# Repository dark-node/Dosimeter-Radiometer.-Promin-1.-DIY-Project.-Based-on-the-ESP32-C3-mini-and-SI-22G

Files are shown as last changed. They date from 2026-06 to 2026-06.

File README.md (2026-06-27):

# Промінь-1 — γ-дозиметр на СІ-22Г / Promin-1 — SI-22G gamma dosimeter

**🇺🇦 Українська** | [🇬🇧 English](README.en.md)

Портативний побутовий гамма-дозиметр на базі лічильної трубки Гейгера–Мюллера
**СІ-22Г** та мікроконтролера **ESP32-C3 Super Mini**.

> ⚠️ **Hobby-проєкт.** Це не сертифікований і не еталонно відкалібрований
> прилад. Не покладайтеся на нього у питаннях здоров'я чи безпеки.
> Зроблено *only for fun*.

## 🎬 Демонстрація роботи

<video src="https://github.com/dark-node/Dosimeter-Radiometer.-Promin-1.-DIY-Project.-Based-on-the-ESP32-C3-mini-and-SI-22G/raw/main/media/demo-test.mp4" controls width="640" poster="media/photos-final/front-view.jpg">
  Ваш переглядач не підтримує вбудоване відео.
</video>

📹 Якщо відео не відтворюється тут — [відкрити / завантажити відео тесту](media/demo-test.mp4)

---

## Можливості

- Реєстрація імпульсів трубки через апаратне переривання (GPIO ISR).
- Розрахунок **CPM** (вікна 60 с і 10 с) та потужності дози **мкЗв/год**.
- OLED-дисплей SSD1306 128×32, три режими: `мкЗв/год`, `CPM`, `cnt`.
- Звуковий клік (п'єзо) і світлодіодний спалах на кожен імпульс.
- Індикація заряду акумулятора (резистивний дільник, опит раз на 2 хв).
- Заставка при старті (2 с).

## Технічні параметри

| Параметр | Значення |
|---|---|
| Трубка | СІ-22Г (гамма) |
| Висока напруга | ~405 В (готовий DC-DC модуль) |
| Анодний баласт | 10 МОм |
| Зняття імпульсу | з катода, формувач на BC547B → GPIO2 |
| Калібрування | 800 CPM на 1 мкЗв/год |
| Фон | ≈0.10–0.12 мкЗв/год |
| MCU | ESP32-C3 Super Mini |
| Дисплей | OLED SSD1306 128×32, I2C 400 кГц |
| Живлення | Li-ion 18650 |

Повний опис, історія розробки та BOM — у [`docs/Description.txt`](docs/Description.txt).

## Розводка GPIO (ESP32-C3)

| GPIO | Призначення |
|---|---|
| 2 | Вхід імпульсів СІ-22Г (ISR) |
| 3 | ADC заряду АКБ |
| 4 / 5 | OLED SDA / SCL |
| 6 | Світлодіод (через 330 Ω) |
| 7 / 10 | П'єзо (push-pull) |
| 8 / 9 / 20 | Кнопки: CPM / мкЗв·год / лічильник |
| 3V3 | Живлення OLED (НЕ 5 В) |

Схема детектора:

```
HV+ ──[10M]── анод СІ-22Г ── катод ── DET
DET ──[10k]── GND
DET ──[470nF]──[50k]── база BC547B ──[4.7M]── GND
емітер ── GND
колектор ──[15k]── 3V3,  відгалуження → GPIO2
```

> ⚡ Не використовувати GPIO0, GPIO1, GPIO21 (boot/UART).
> Спільна земля: ESP, HV-модуль, катод трубки, емітер транзистора.

## Структура репозиторію

```
.
├── firmware/             # Прошивка ESP-IDF (C/C++)
│   └── main/main.cpp
├── hardware/
│   ├── schematics/       # LTspice: схема з'єднань + симуляції
│   └── 3d-models/        # STL/Blender корпусу + renders/
├── media/
│   ├── photos-final/     # Фото готового пристрою
│   ├── photos-build/     # Фото процесу збірки
│   └── demo-test.mp4     # Відео тесту роботи
├── docs/
│   ├── Description.txt    # Опис, історія, BOM, специфікація
│   └── splash.png         # Вихідне зображення заставки OLED
├── LICENSE               # MIT
├── README.md             # Українська (цей файл)
└── README.en.md          # English
```

## Складання та прошивка

Потрібен [ESP-IDF](https://docs.espressif.com/projects/esp-idf/). У теці `firmware/`:

```bash
idf.py set-target esp32c3
idf.py build
idf.py flash monitor
```

## Схема (LTspice)

Файл [`hardware/schematics/promin1-connections.asc`](hardware/schematics/promin1-connections.asc)
— схема з'єднань для збірки (довідник, не для симуляції).

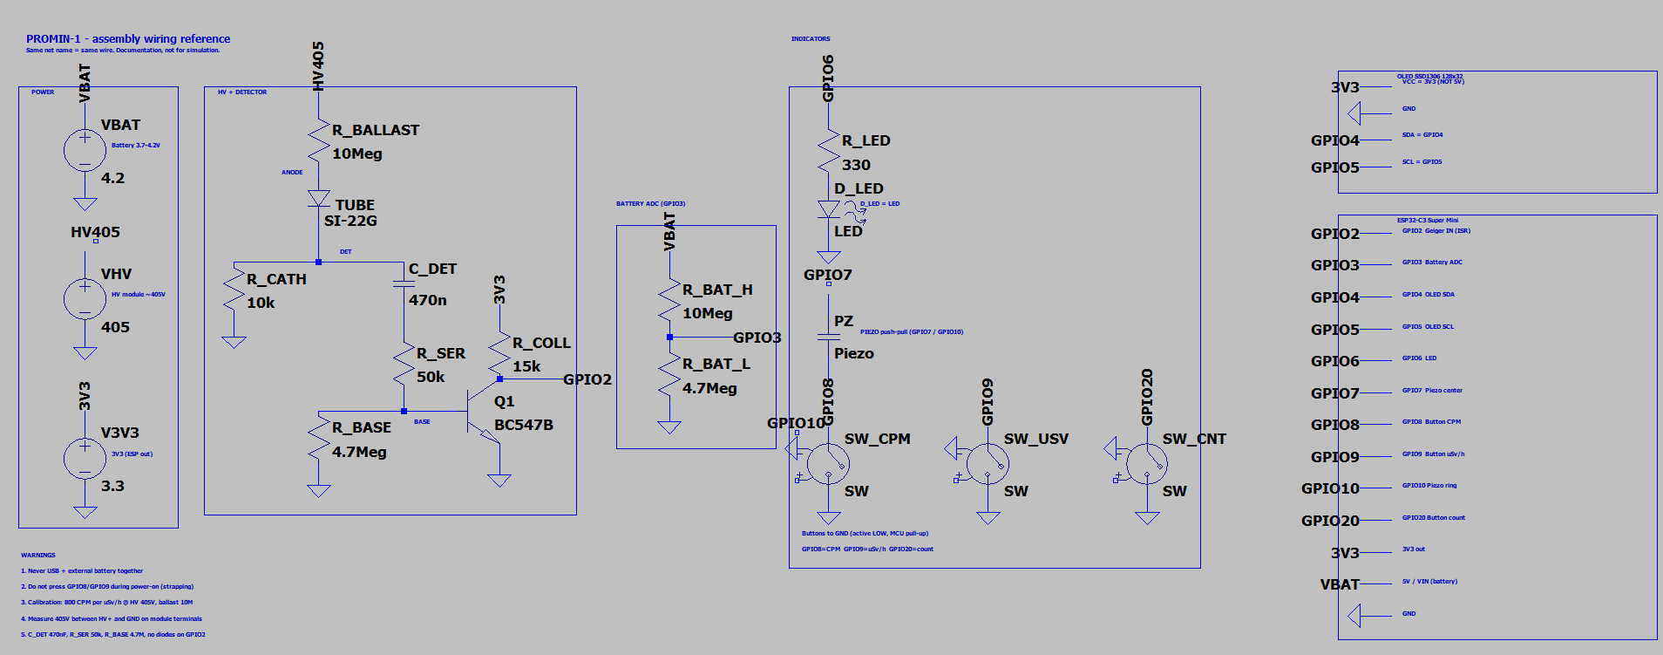
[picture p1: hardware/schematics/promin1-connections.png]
Schematic


## Галерея

| | | |
|---|---|---|
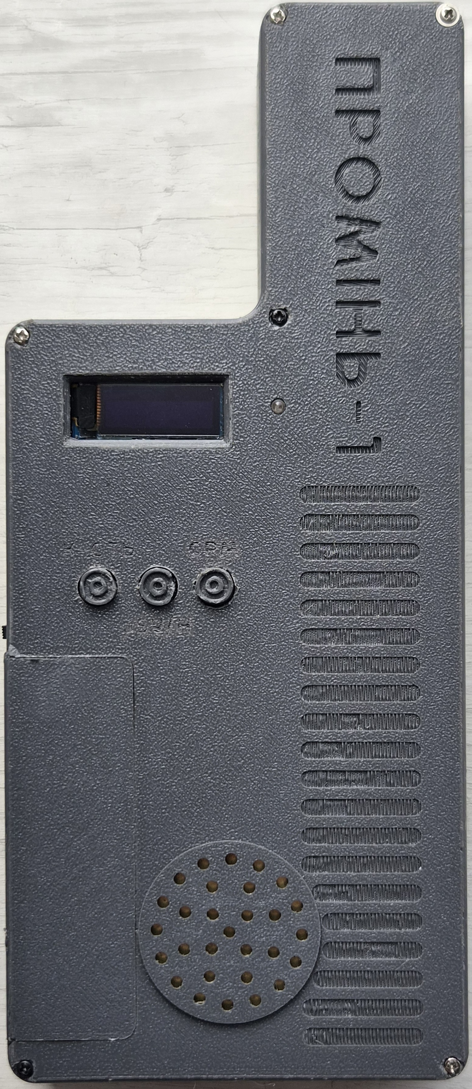
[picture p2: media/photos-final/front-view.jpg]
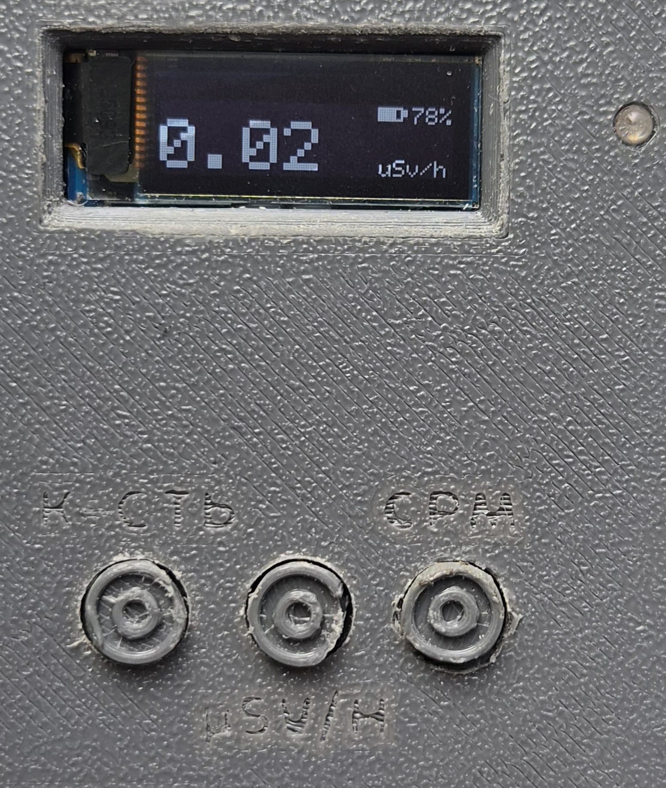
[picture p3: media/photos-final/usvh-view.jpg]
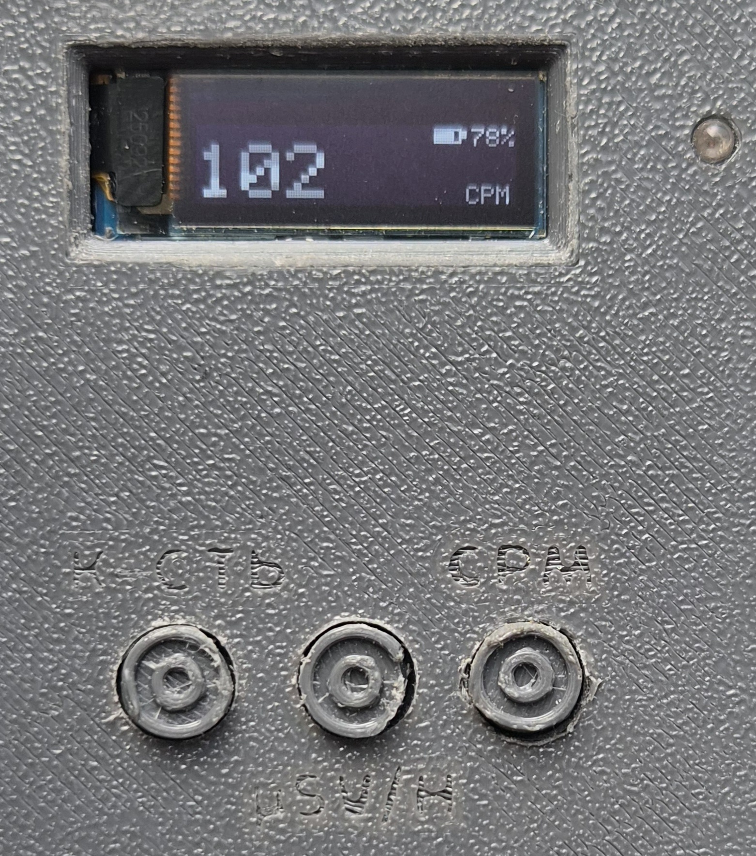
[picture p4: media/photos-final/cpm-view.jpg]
|  |  |  |
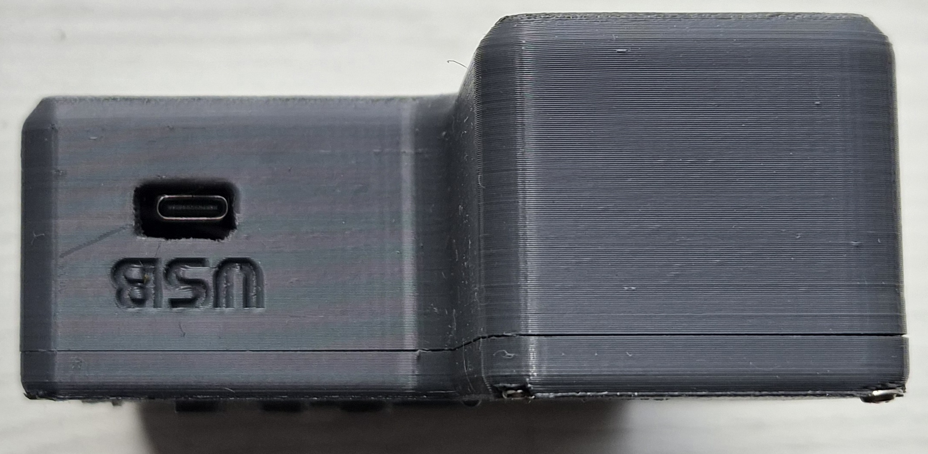
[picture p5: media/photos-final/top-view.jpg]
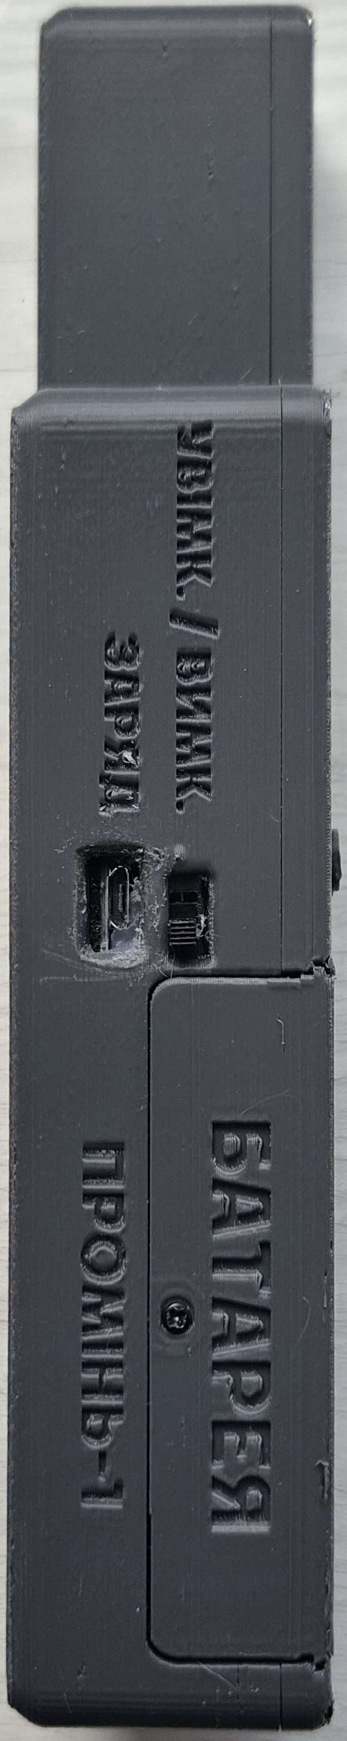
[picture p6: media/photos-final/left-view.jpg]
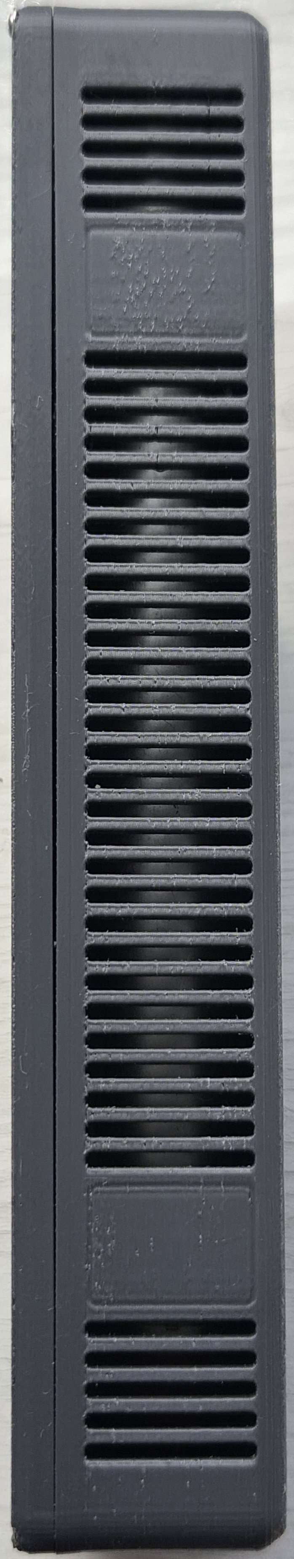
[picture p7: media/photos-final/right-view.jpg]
|  |  |  |

3D-моделі корпусу: [`hardware/3d-models/`](hardware/3d-models/)

## Ліцензія

[MIT](LICENSE). Hobby-пристрій, use at your own risk.

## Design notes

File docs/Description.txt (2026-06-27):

================================================================
ПРОМІНЬ-1 — портативний гамма-дозиметр на СІ-22Г
================================================================

--------------------------------
ВІД АВТОРА
--------------------------------

Збірка дозиметра «Промінь-1» за своєю суттю — лише хобійний експеримент.
Корисної інформації в цьому проєкті доволі мало, і немає жодних наукових
відкриттів. Більше того, професіонали своєї справи можуть дуже легко знайти
слабкі або неправильні місця — і будуть цілком праві. Цей проєкт фактично є
здійсненням дитячої мрії з тих часів, коли я вперше навчився паяти, — і не
більше того.

Тому радіоаматори можуть «захейтити» за надто грубий спосіб зняття імпульсів
та за використання готового модуля високої напруги замість намотування власних
котушок — але це й не було прямою метою цієї роботи. Своєю чергою, любителі
радіодозиметрії можуть «захейтити» за відсутність другого, еталонного дозиметра
й за неточність роботи пристрою. Але повторюся: ця робота була створена only
for fun і супернаукової цінності не несе.

Саме через це було обрано трубку СІ-22Г: вона дешева, до того ж куплена «з рук»
(вживана). Щоправда, через це довелося доволі сильно збільшити розміри готового
виробу. Знімати імпульси довелося з катода (хоча там вони на порядок слабші);
при цьому були спроби зняти сигнал як транзистором, так і оптопарою — спрацював
лише один варіант. Анодний спосіб навіть не довелося пробувати. А калібрування
(через відсутність еталонного пристрою) довелося робити за станціями, що
вимірюють радіацію в моїй зоні проживання, — тому ймовірність похибки в цьому
пристрої доволі велика. Більше того, довелося підвищувати напругу до 420–440 В
(у фінальній версії подається 405 В) через «заюзаність» самої трубки, яка
фактично за паспортних умов видає лише близько 30–40 імпульсів (а мала б 60+).

Також для тих, хто захоче повторити: обов'язково майте набір резисторів,
особливо кілоомних, — тому що під вашу конкретну трубку доведеться підбирати
такий опір, щоб імпульси, які ви знімаєте, мали достатню амплітуду й були
помітні для вашого MCU.

Щодо візуалу — так-так, 3D-друк вийшов доволі поганеньким, але передруковувати
не бачу великого сенсу: у ролі корпусу він функціонує нормально, та й подальша
доля цього дозиметра — лежати в шафі. Можливо, через деякий час він навіть буде
розібраний на компоненти. Тому для цієї ролі все чудово підходить і так.

Декілька слів про MCU. Спочатку для збірки використовувалася ESP32-H2 — з тієї
причини, що вона просто була в мене. Але в процесі роботи вона перестала
адекватно працювати, тому було вирішено не витрачати ні час, ні гроші, а взяти з
іншого проєкту ESP32-C3, яка більше підходить для виконання цього завдання, а
також лишає можливість додати Wi-Fi-підключення й модифікувати дозиметр для
роботи через хот-спот. Але це не було реалізовано (мені то й не треба).

--------------------------------
ОПИС ПРОЄКТУ
--------------------------------

«Промінь-1» — портативний лічильник іонізуючого випромінювання (побутовий
гамма-дозиметр) на базі радянської лічильної трубки Гейгера-Мюллера СІ-22Г та
мікроконтролера ESP32-C3 Super Mini.

Принцип роботи:
  1. DC-DC модуль підвищує напругу живлення до ~405 В для роботи трубки.
  2. Кожна зареєстрована частинка викликає короткий розряд у трубці.
  3. Імпульс знімається з катода, формується транзистором BC547B і подається
     на вхід MCU (GPIO2) як перепад рівня, що обробляється через апаратне
     переривання (GPIO ISR).
  4. Прошивка рахує імпульси, обчислює CPM (за вікно 60 с і за вікно 10 с) та
     переводить у потужність дози (мкЗв/год) за калібрувальним коефіцієнтом.
  5. Результат виводиться на OLED-дисплей; кожен імпульс супроводжується кліком
     п'єзовипромінювача та спалахом світлодіода.

Режими відображення (перемикаються кнопками):
  - мкЗв/год  — потужність дози (за усередненим CPM60), екран за замовчуванням;
  - CPM       — швидкий темп лічби (за вікно 10 с);
  - cnt       — сумарна кількість зареєстрованих імпульсів.

Додатково на екрані відображається рівень заряду акумулятора (вимірюється через
резистивний дільник раз на 2 хв).

Калібрування: GEIGER_CPM_PER_USVH = 800 (≈100 CPM60 ≈ 0.126 мкЗв/год за фоном,
звірено зі станцією Safecast 126 нЗв/год). Через вживану трубку та відсутність
еталона точність орієнтовна.

--------------------------------
ЩО ВИКОРИСТОВУВАЛОСЬ
--------------------------------

Апаратне забезпечення:
  - Мікроконтролер ESP32-C3 Super Mini (RISC-V, Wi-Fi/BLE — не задіяні).
  - Трубка Гейгера-Мюллера СІ-22Г (гамма, вживана).
  - Готовий DC-DC модуль високої напруги (вхід 5 В, вихід ~405 В).
  - OLED-дисплей SSD1306 128x32, інтерфейс I2C.
  - Акумулятор Li-ion 18650.

Інструменти та ПЗ:
  - ESP-IDF (фреймворк, мова C/C++), збірка через idf.py.
  - LTspice — схема з'єднань для збірки (файл Schematic/Promin1.asc).
  - 3D-друк корпусу (моделі в теці 3D_models).
  - Паяння методом «навісного монтажу» (point-to-point), згодом — на платі.

--------------------------------
СПИСОК КОМПОНЕНТІВ (BOM)
--------------------------------

  Поз.        Номінал / тип        К-сть   Призначення
  ----------  -------------------  ------  -------------------------------------
  MCU         ESP32-C3 Super Mini    1     Керування, лічба, дисплей
  Трубка      СІ-22Г                 1     Детектор гамма-випромінювання
  HV-модуль   DC-DC ~405 В (вх.5В)   1     Висока напруга для трубки
  Дисплей     OLED SSD1306 128x32    1     Індикація (I2C)
  АКБ         Li-ion 18650           1     Живлення
  Q1          BC547B (NPN)           1     Формувач імпульсу з катода
  R_BALLAST   10 МОм                 1     Анодний баласт (HV+ → анод)
  R_CATH      10 кОм                 1     Катодне навантаження (DET → GND)
  R_SER       50 кОм                 1     Послідовний у базу (через C_DET)
  R_BASE      4.7 МОм                1     Зміщення/стік бази → GND
  R_COLL      15 кОм                 1     Колектор → 3.3 В (підтяжка)
  R_LED       330 Ом                 1     Струмообмеження світлодіода
  R_BAT_H     10 МОм                 1     Верхнє плече дільника АКБ
  R_BAT_L     4.7 МОм                1     Нижнє плече дільника АКБ
  C_DET       470 нФ                 1     Розв'язка катод → база
  D_LED       Світлодіод             1     Індикація імпульсів
  Піщалка     П'єзовипромінювач      1     Звуковий клік (push-pull)
  Кнопки      Тактові, на GND        3     Перемикання режимів
  ----------  -------------------  ------  -------------------------------------

  Примітка: кілоомні номінали (R_CATH, R_SER) підбираються індивідуально під
  конкретну трубку — тримайте під рукою набір резисторів.

--------------------------------
СПЕЦИФІКАЦІЯ / РОЗВОДКА GPIO
--------------------------------

  Детектор:
    HV+ ──[R_BALLAST 10M]── анод СІ-22Г ── катод ── DET
    DET ──[R_CATH 10k]── GND
    DET ──[C_DET 470n]──[R_SER 50k]── база BC547B
    база ──[R_BASE 4.7M]── GND
    емітер ── GND
    колектор ──[R_COLL 15k]── 3.3 В,  відгалуження → GPIO2

  Дільник вимірювання АКБ:
    VBAT ──[R_BAT_H 10M]── GPIO3 ──[R_BAT_L 4.7M]── GND

  Призначення виводів ESP32-C3 (мітка на платі = номер GPIO):
    GPIO2   — вхід імпульсів СІ-22Г (через ISR, спадний фронт)
    GPIO3   — ADC вимірювання заряду АКБ
    GPIO4   — OLED SDA (I2C)
    GPIO5   — OLED SCL (I2C)
    GPIO6   — світлодіод (через 330 Ом)
    GPIO7   — п'єзо, центральний (push-pull, фаза A)
    GPIO8   — кнопка «CPM»
    GPIO9   — кнопка «мкЗв/год» (екран)
    GPIO10  — п'єзо, кільце (push-pull, фаза B)
    GPIO20  — кнопка «лічильник»
    3V3     — живлення OLED (НЕ 5 В!)
    5V/VIN  — від акумулятора
    GND     — спільна земля

  Не використовувати: GPIO0, GPIO1, GPIO21 (boot/UART).
  Спільна земля: ESP, HV-модуль, катод трубки, емітер транзистора.

  Ключові параметри прошивки:
    - Висока напруга:            405 В (вимір між HV+ і GND на модулі)
    - Калібрування:              800 CPM на 1 мкЗв/год
    - Вікна усереднення:         60 с (доза) і 10 с (швидкий CPM)
    - Антидребезг трубки:        2500 мкс
    - Опитування АКБ:            раз на 2 хв
    - Заставка при старті:       2 с (інвертовані кольори)
    - Дисплей:                   SSD1306 128x32, I2C 400 кГц

--------------------------------
СТРУКТУРА РЕПОЗИТОРІЮ
--------------------------------

  Promin1/         — прошивка ESP-IDF (main/main.cpp, splash_bitmap.h)
  Schematic/       — схема з'єднань для LTspice (Promin1.asc)
  3D_models/       — моделі корпусу для друку (+ Img з рендерами)
  Final_Photos/    — фото готового пристрою
  Develop_photos/  — фото процесу збірки
  Video/           — відео тесту роботи (Video_test.mp4)
  splash_img.png   — вихідне зображення заставки OLED
  Description.txt  — цей файл

================================================================
Створено as a hobby. Use at your own risk. Only for fun.
================================================================

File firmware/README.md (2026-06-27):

# Promin-1 — прошивка (ESP-IDF)

Прошивка γ-дозиметра «Промінь-1» для **ESP32-C3 Super Mini**.

Основний код: [`main/main.cpp`](main/main.cpp)
Заставка OLED: [`main/splash_bitmap.h`](main/splash_bitmap.h)

## Складання

```bash
idf.py set-target esp32c3
idf.py build
idf.py flash monitor
```

## Ключові константи (main.cpp)

| Константа | Значення | Призначення |
|---|---|---|
| `GEIGER_CPM_PER_USVH` | 800 | Калібрування CPM → мкЗв/год |
| `GEIGER_CPM_WINDOW_SEC` | 60 | Вікно усереднення дози |
| `GEIGER_CPM_INST_SEC` | 10 | Вікно швидкого CPM |
| `GEIGER_DEADTIME_US` | 2500 | Антидребезг трубки |
| `BAT_CHECK_MS` | 120000 | Період опитування АКБ |
| `SPLASH_MS` | 2000 | Тривалість заставки |
| `SPLASH_INVERT_COLORS` | 1 | Інверсія кольорів заставки |

## Розводка GPIO

Див. коментар на початку `main/main.cpp` і `README.md` у корені репозиторію.

> Заставку OLED можна перегенерувати з PNG скриптом `tools/png2splash.py`
> (якщо він присутній): `py -3 tools/png2splash.py docs/splash.png -o firmware/main/splash_bitmap.h`

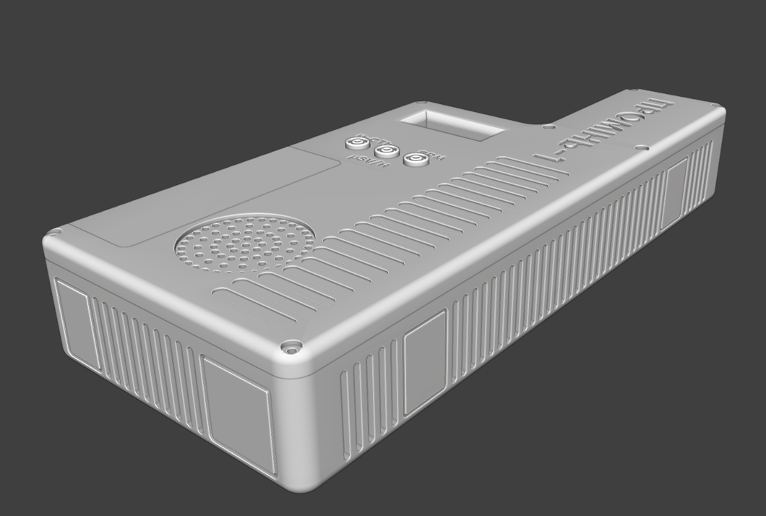
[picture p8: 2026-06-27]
hardware/3d-models/renders/render-2.png

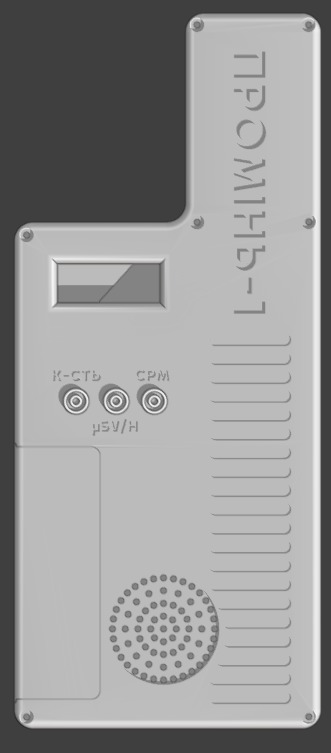
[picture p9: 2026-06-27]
hardware/3d-models/renders/render-3.png

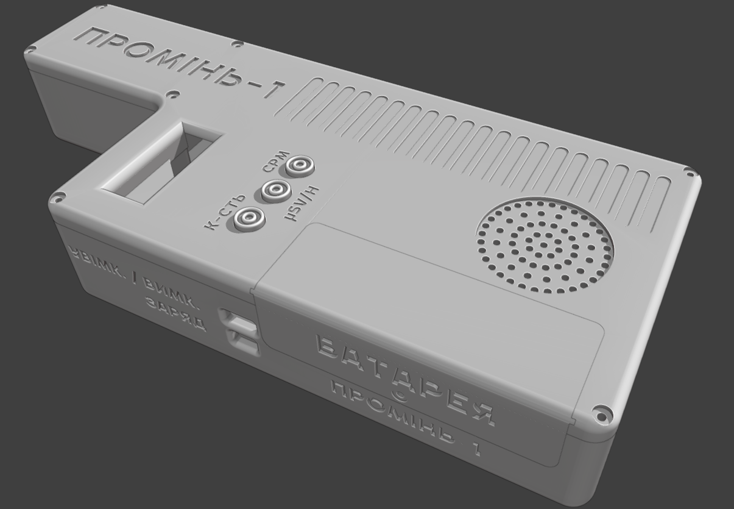
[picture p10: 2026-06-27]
hardware/3d-models/renders/render-1.png

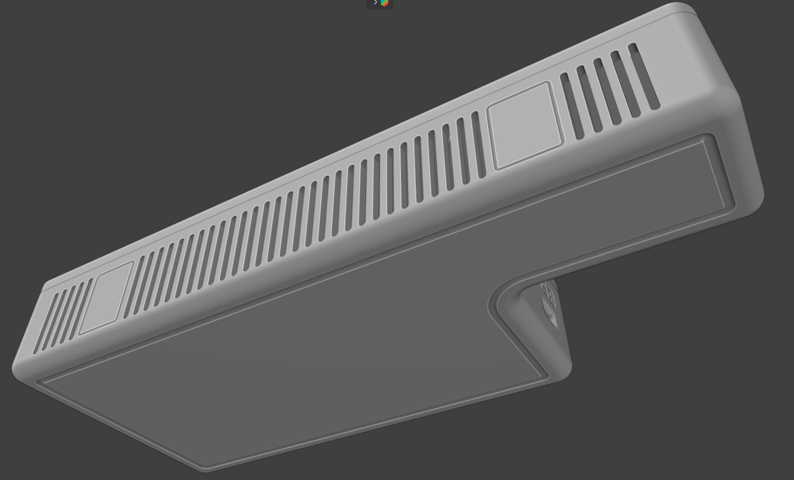
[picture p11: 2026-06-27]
hardware/3d-models/renders/render-4.png

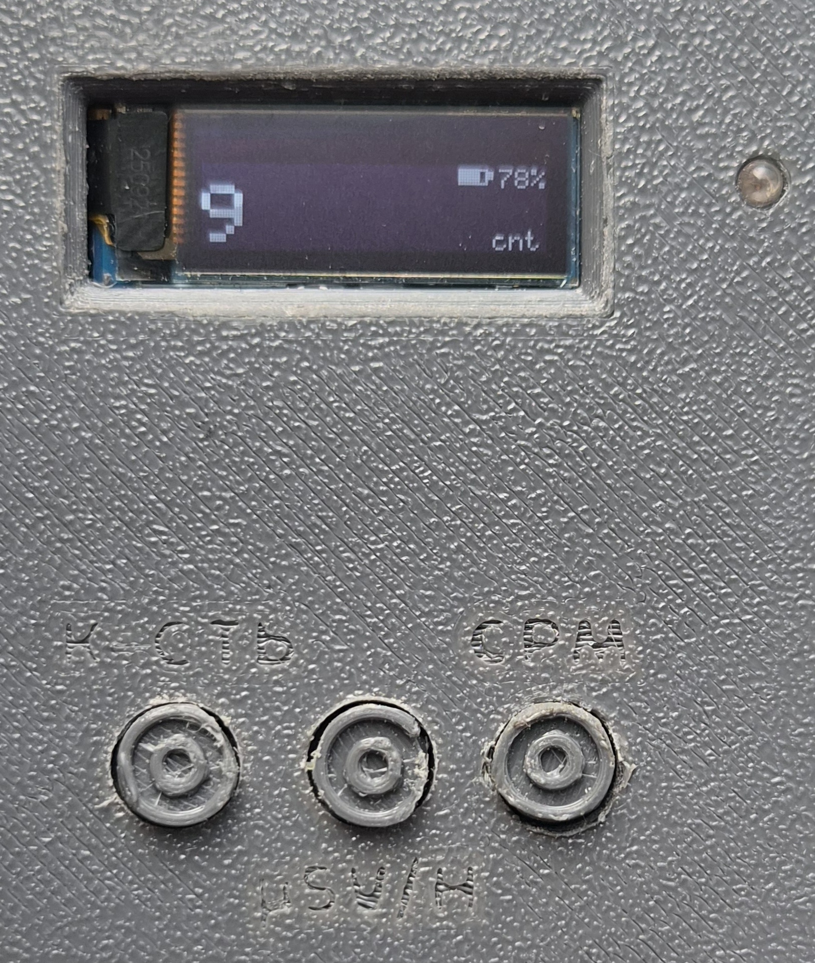
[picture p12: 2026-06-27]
media/photos-final/count-view.jpg

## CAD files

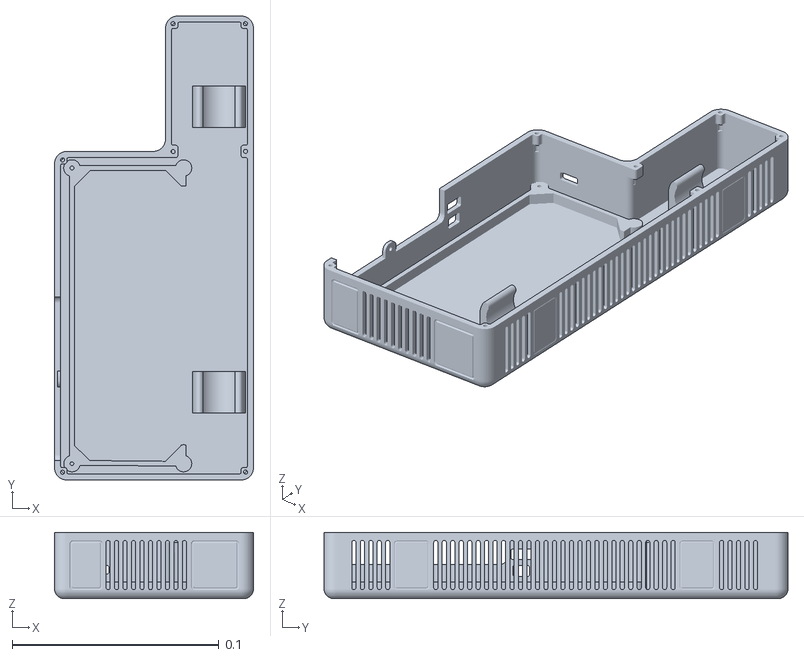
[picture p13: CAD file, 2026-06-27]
hardware/3d-models/base-bottom.stl
0.0963 x 0.224 x 0.0321

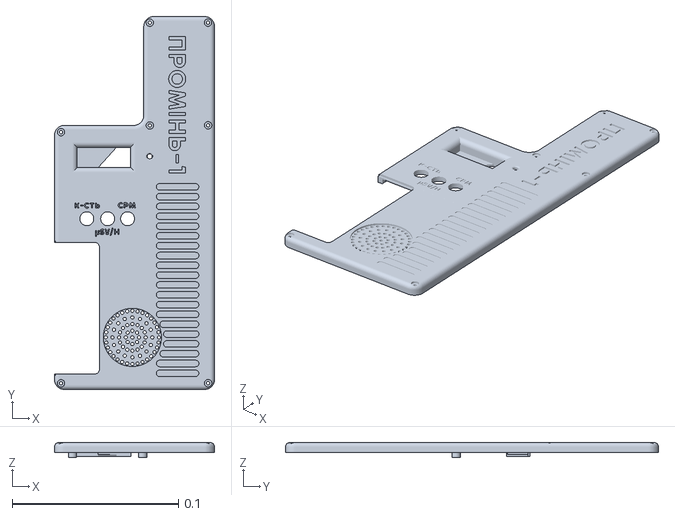
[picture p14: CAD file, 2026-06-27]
hardware/3d-models/base-top.stl
0.0963 x 0.224 x 0.00906

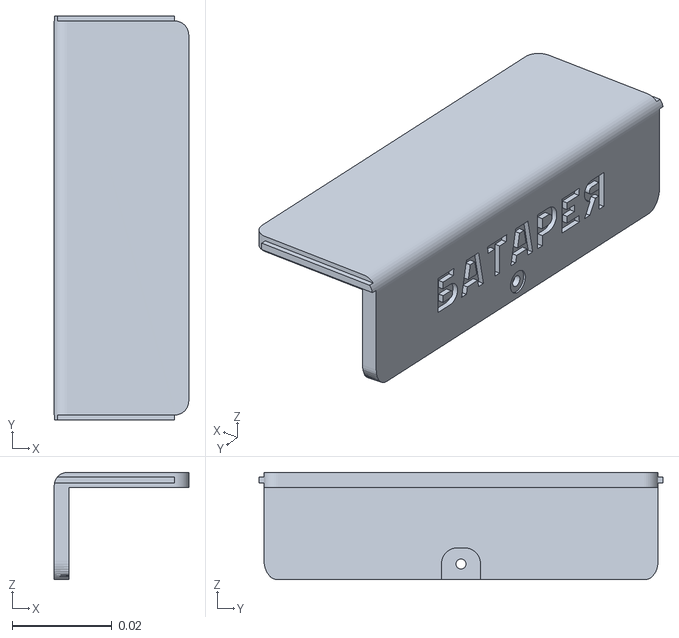
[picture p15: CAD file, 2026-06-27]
hardware/3d-models/battery-part.stl
0.027 x 0.0811 x 0.0215

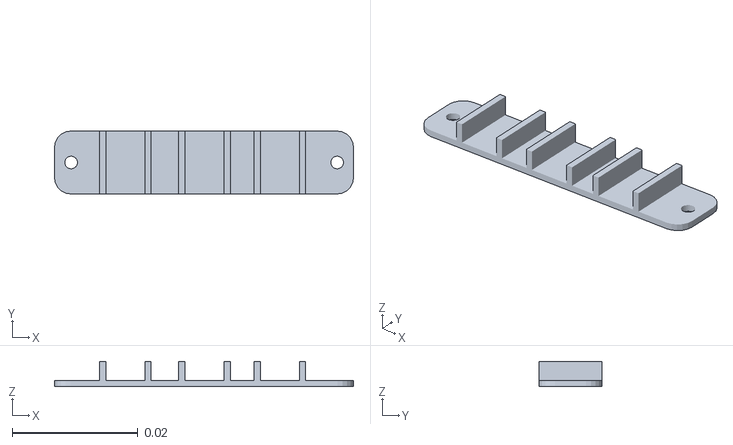
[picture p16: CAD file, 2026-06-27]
hardware/3d-models/button-plate.stl
0.0475 x 0.01 x 0.004

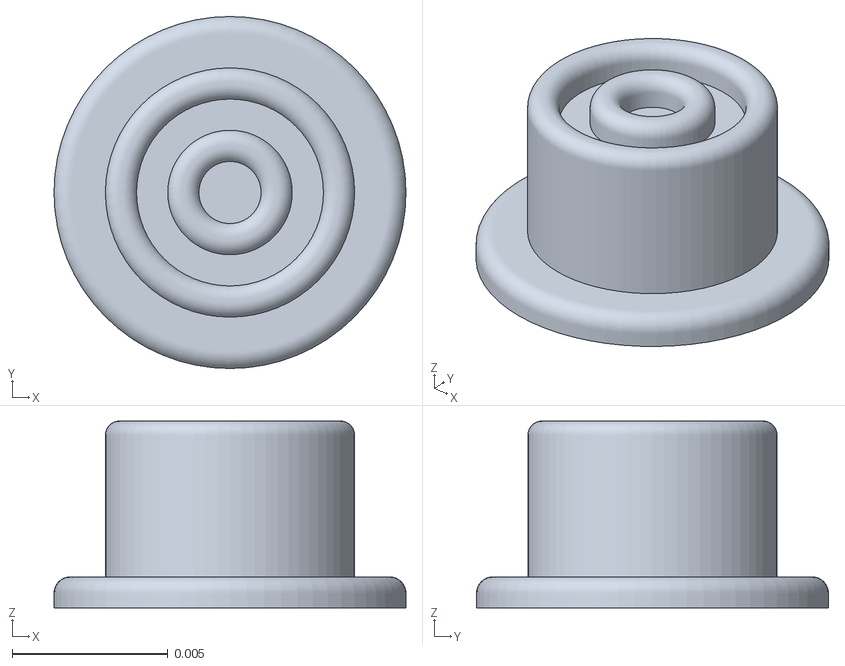
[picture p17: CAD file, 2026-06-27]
hardware/3d-models/button-3.stl
0.0113 x 0.0113 x 0.006

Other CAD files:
hardware/3d-models/button-2.stl
hardware/3d-models/button-1.stl
hardware/3d-models/box.blend

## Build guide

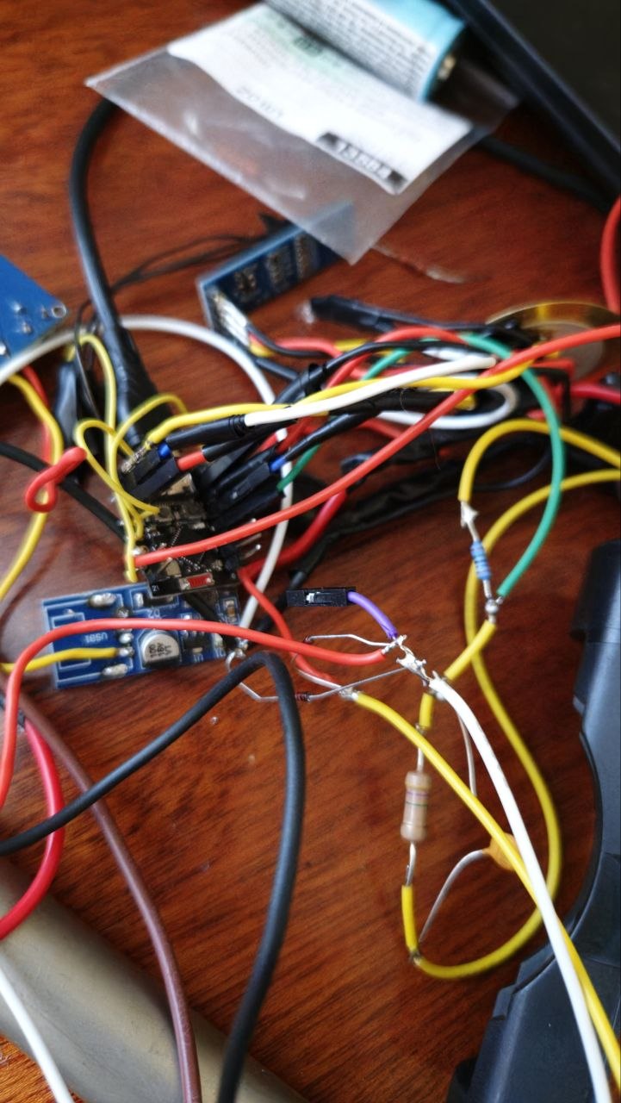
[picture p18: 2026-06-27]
media/photos-build/build-1.jpg

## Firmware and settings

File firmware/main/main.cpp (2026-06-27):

/**
 * SI22G Dosimeter — тестова прошивка ESP32-C3 Super Mini
 *
 * Розводка (мітки на платі = номер GPIO):
 *   OLED SSD1306 128x32 I2C : SDA=4,  SCL=5
 *   LED                     : 6  → 330 Ω → анод, катод → G
 *   П'єзо push-pull         : 7 (центр), 10 (кільце)
 *     фаза A: 7=HIGH, 10=LOW  |  фаза B: 7=LOW, 10=HIGH
 *     T=400 мкс (2500 Гц), півперіод=200 мкс
 *   АКБ (дільник 10M+4.7M)  : 3  — точка МІЖ 10M і 4.7M
 *   СИ-22Г (імпульси)       : 2  — BC547 колектор → 15k → 3.3V, спад на GPIO (ISR)
 *     HV модуль 405V (вимір HV+↔GND), баласт анод 10MΩ
 *     детектор: база 4.7M→GND, 100nF→470nF DET→база (рекомендовано на платі)
 *   Кнопки → GND            : 8 → CPM, 9 → µSv/h (екран), 20 → лічильник
 *   Живлення OLED           : 3.3 (НЕ 5V!)
 *
 * Не використовувати: 0, 1 (boot/UART). GPIO8/9 — strapping, не тиснути при увімкненні.
 * GPIO20/21 — консоль UART, не підключати сюди детектор.
 * USB + зовнішнє 3.3 V одночасно — ЗАБОРОНЕНО.
 */

#include <stdio.h>
#include <string.h>
#include <stdint.h>
#include <stdbool.h>

#include "freertos/FreeRTOS.h"
#include "freertos/task.h"
#include "freertos/semphr.h"
#include "esp_log.h"
#include "esp_err.h"
#include "esp_check.h"
#include "esp_rom_sys.h"
#include "esp_timer.h"
#include "driver/gpio.h"
#include "driver/i2c_master.h"
#include "esp_adc/adc_oneshot.h"
#include "esp_adc/adc_cali.h"
#include "esp_adc/adc_cali_scheme.h"
#include "esp_lcd_panel_io.h"
#include "esp_lcd_panel_ops.h"
#include "esp_lcd_panel_vendor.h"
#include "esp_lcd_panel_ssd1306.h"

#include "splash_bitmap.h"

static const char *TAG = "SI22G_TEST";

/* ── Піни ESP32-C3 Super Mini (мітка на платі = GPIO) ───────────────────── */
#define PIN_OLED_SDA      GPIO_NUM_4
#define PIN_OLED_SCL      GPIO_NUM_5
#define PIN_LED           GPIO_NUM_6
#define PIN_PIEZO_CENTER  GPIO_NUM_7
#define PIN_PIEZO_RING    GPIO_NUM_10
#define PIN_BAT_ADC       GPIO_NUM_3
#define PIN_BTN_1         GPIO_NUM_8   /* → CPM */
#define PIN_BTN_2         GPIO_NUM_9   /* → µSv/h */
#define PIN_BTN_3         GPIO_NUM_20  /* → лічильник імпульсів */
#define PIN_GEIGER        GPIO_NUM_2

/* ── СИ-22Г: зчитування імпульсів ─────────────────────────────────────────── */
#define GEIGER_DEADTIME_US      2500      /* антидребезг BC547, мкс */
#define GEIGER_CPM_WINDOW_SEC   60
#define GEIGER_CPM_INST_SEC     10        /* швидкий CPM (режим CPM на OLED) */
#define GEIGER_CPM_PER_USVH     800.0f    /* ~100 CPM60 @ 0.126 µSv/h, HV 405V, Safecast 126 nSv/h */
#define GEIGER_STATS_PERIOD_MS  1000

/* ── АКБ: дільник 10 MΩ / 4.7 MΩ ─────────────────────────────────────────── */
#define BAT_ADC_ATTEN         ADC_ATTEN_DB_6    /* Vadc 0.3–1.34 V, не DB_11 */
#define BAT_DIVIDER_RATIO     3.12766f          /* (10 + 4.7) / 4.7 */
#define BAT_ADC_VREF_MV       1300              /* ~макс. на GPIO при DB_6 (C3) */
#define BAT_ADC_RAW_SAT       4000
#define BAT_VOLTAGE_FULL      4.2f
#define BAT_VOLTAGE_EMPTY     3.3f
#define BAT_ADC_SAMPLES       8
#define BAT_ADC_SAMPLE_MS     20
#define BAT_ADC_INVALID_V     (-1.0f)
#define BAT_CHECK_MS            120000    /* опит АКБ раз на 2 хв */
#define BAT_ADC_SAMPLES_QUICK   4
#define BAT_ADC_SAMPLE_MS_QUICK 5
#define SPLASH_MS               2000
#define SPLASH_INVERT_COLORS    1   /* тест: 1 = інверсія, 0 = як у PNG */

/* ── OLED UI (128×32) ─────────────────────────────────────────────────────── */
#define OLED_I2C_ADDR           0x3C
#define OLED_I2C_HZ             (400 * 1000)
#define OLED_WIDTH              128
#define OLED_HEIGHT             32
#define OLED_BUF_SIZE           (OLED_WIDTH * OLED_HEIGHT / 8)
#define UI_STATUS_H             8
#define UI_DOSE_Y               8
#define UI_DOSE_SCALE           3
#define UI_DOSE_X               0         /* значення дози — максимум ліворуч */
#define UI_UNIT_Y               24
#define UI_UNIT_MARGIN          2         /* відступ одиниці від правого краю */
#define BAT_ICON_BODY_W         11
#define BAT_ICON_BODY_H         6
#define BAT_ICON_CAP_W          2
#define BAT_ICON_CAP_H          3

/* ── Кнопки (активний LOW → GND) ─────────────────────────────────────────── */
#define BTN_COUNT               3
#define BTN_DEBOUNCE_MS         50

/* ── LED: короткий спалах на кожен імпульс ───────────────────────────────── */
#define LED_PULSE_US            25000

/* ── П'єзо: клік на реальний імпульс трубки ──────────────────────────────── */
#define PIEZO_HALF_PERIOD_US    200
#define PIEZO_BURST_MS          1         /* короткий тик на кожен імпульс */
#define PIEZO_TICK_QUEUE_MAX    8

/* ── Шрифт 6×8 (ASCII 32–127) ─────────────────────────────────────────────── */
#define FONT_CHAR_W  6
#define FONT_CHAR_H  8

static const uint8_t font6x8[96][8] = {
    {0x00,0x00,0x00,0x00,0x00,0x00,0x00,0x00}, /* space */
    {0x00,0x00,0x5F,0x00,0x00,0x00,0x00,0x00}, /* ! */
    {0x00,0x07,0x00,0x07,0x00,0x00,0x00,0x00}, /* " */
    {0x14,0x7F,0x14,0x7F,0x14,0x00,0x00,0x00}, /* # */
    {0x24,0x2A,0x7F,0x2A,0x12,0x00,0x00,0x00}, /* $ */
    {0x23,0x13,0x08,0x64,0x62,0x00,0x00,0x00}, /* % */
    {0x36,0x49,0x55,0x22,0x50,0x00,0x00,0x00}, /* & */
    {0x00,0x05,0x03,0x00,0x00,0x00,0x00,0x00}, /* ' */
    {0x00,0x1C,0x22,0x41,0x00,0x00,0x00,0x00}, /* ( */
    {0x00,0x41,0x22,0x1C,0x00,0x00,0x00,0x00}, /* ) */
    {0x14,0x08,0x3E,0x08,0x14,0x00,0x00,0x00}, /* * */
    {0x08,0x08,0x3E,0x08,0x08,0x00,0x00,0x00}, /* + */
    {0x00,0x50,0x30,0x00,0x00,0x00,0x00,0x00}, /* , */
    {0x08,0x08,0x08,0x08,0x08,0x00,0x00,0x00}, /* - */
    {0x00,0x60,0x60,0x00,0x00,0x00,0x00,0x00}, /* . */
    {0x20,0x10,0x08,0x04,0x02,0x00,0x00,0x00}, /* / */
    {0x3E,0x51,0x49,0x45,0x3E,0x00,0x00,0x00}, /* 0 */
    {0x00,0x42,0x7F,0x40,0x00,0x00,0x00,0x00}, /* 1 */
    {0x42,0x61,0x51,0x49,0x46,0x00,0x00,0x00}, /* 2 */
    {0x21,0x41,0x45,0x4B,0x31,0x00,0x00,0x00}, /* 3 */
    {0x18,0x14,0x12,0x7F,0x10,0x00,0x00,0x00}, /* 4 */
    {0x27,0x45,0x45,0x45,0x39,0x00,0x00,0x00}, /* 5 */
    {0x3C,0x4A,0x49,0x49,0x30,0x00,0x00,0x00}, /* 6 */
    {0x01,0x71,0x09,0x05,0x03,0x00,0x00,0x00}, /* 7 */
    {0x36,0x49,0x49,0x49,0x36,0x00,0x00,0x00}, /* 8 */
    {0x06,0x49,0x49,0x29,0x1E,0x00,0x00,0x00}, /* 9 */
    {0x00,0x36,0x36,0x00,0x00,0x00,0x00,0x00}, /* : */
    {0x00,0x56,0x36,0x00,0x00,0x00,0x00,0x00}, /* ; */
    {0x08,0x14,0x22,0x41,0x00,0x00,0x00,0x00}, /* < */
    {0x14,0x14,0x14,0x14,0x14,0x00,0x00,0x00}, /* = */
    {0x00,0x41,0x22,0x14,0x08,0x00,0x00,0x00}, /* > */
    {0x02,0x01,0x51,0x09,0x06,0x00,0x00,0x00}, /* ? */
    {0x32,0x49,0x79,0x41,0x3E,0x00,0x00,0x00}, /* @ */
    {0x7E,0x11,0x11,0x11,0x7E,0x00,0x00,0x00}, /* A */
    {0x7F,0x49,0x49,0x49,0x36,0x00,0x00,0x00}, /* B */
    {0x3E,0x41,0x41,0x41,0x22,0x00,0x00,0x00}, /* C */
    {0x7F,0x41,0x41,0x22,0x1C,0x00,0x00,0x00}, /* D */
    {0x7F,0x49,0x49,0x49,0x41,0x00,0x00,0x00}, /* E */
    {0x7F,0x09,0x09,0x09,0x01,0x00,0x00,0x00}, /* F */
    {0x3E,0x41,0x49,0x49,0x7A,0x00,0x00,0x00}, /* G */
    {0x7F,0x08,0x08,0x08,0x7F,0x00,0x00,0x00}, /* H */
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
    {0x00,0x00,0x00,0x00,0x00,0x00,0x00,0x00}, /* DEL placeholder */
};

static i2c_master_bus_handle_t s_i2c_bus = NULL;
static esp_lcd_panel_handle_t s_panel = NULL;
static SemaphoreHandle_t s_oled_mtx = NULL;
static uint8_t s_oled_buf[OLED_BUF_SIZE];
static bool s_splash_active = false;
static adc_oneshot_unit_handle_t s_adc_handle = NULL;
static adc_cali_handle_t s_adc_cali_handle = NULL;
static adc_channel_t s_bat_channel = ADC_CHANNEL_2;
static bool s_adc_cali_ok = false;
static int s_bat_last_raw = 0;
static int s_bat_display_pct = -1;      /* -1 = ще немає усередненого значення */
static uint32_t s_bat_last_check_ms = 0;
static int s_display_mode = 1;          /* 0=CPM, 1=µSv/h (за замовч.), 2=total */
static int s_display_value = 0;
static int s_cpm = 0;
static int s_cpm_inst = 0;
static volatile uint32_t s_pulse_isr_total = 0;
static volatile int64_t s_last_pulse_us = 0;
static uint32_t s_sec_buckets[GEIGER_CPM_WINDOW_SEC];
static int s_bucket_idx = 0;
static uint32_t s_sec_pulse_count = 0;
static uint32_t s_last_isr_total = 0;
static volatile uint32_t s_gpio_low_samples = 0;
static int64_t s_last_commit_sec = -1;
static volatile int64_t s_led_off_us = 0;
static volatile uint32_t s_pending_piezo_ticks = 0;
static volatile bool s_geiger_armed = true;

static void IRAM_ATTR geiger_on_pulse(int64_t now_us)
{
    s_geiger_armed = false;
    s_last_pulse_us = now_us;
    s_pulse_isr_total = s_pulse_isr_total + 1;
    gpio_set_level(PIN_LED, 1);
    s_led_off_us = now_us + LED_PULSE_US;
    if (s_pending_piezo_ticks < PIEZO_TICK_QUEUE_MAX) {
        s_pending_piezo_ticks++;
    }
}

static void IRAM_ATTR geiger_gpio_isr(void *arg)
{
    (void)arg;
    const int level = gpio_get_level(PIN_GEIGER);
    if (level == 1) {
        s_geiger_armed = true;
        return;
    }
    if (!s_geiger_armed) {
        return;
    }
    const int64_t now = esp_timer_get_time();
    if ((now - s_last_pulse_us) < GEIGER_DEADTIME_US) {
        return;
    }
    geiger_on_pulse(now);
}

static void geiger_recalc_cpm(void)
{
    uint32_t sum = 0;
    uint32_t sum_inst = 0;
    for (int i = 0; i < GEIGER_CPM_WINDOW_SEC; i++) {
        sum += s_sec_buckets[i];
    }
    for (int i = 0; i < GEIGER_CPM_INST_SEC; i++) {
        const int idx = (s_bucket_idx - 1 - i + GEIGER_CPM_WINDOW_SEC) % GEIGER_CPM_WINDOW_SEC;
        sum_inst += s_sec_buckets[idx];
    }
    s_cpm = (int)sum;
    s_cpm_inst = (int)(sum_inst * 60 / GEIGER_CPM_INST_SEC);

    s_display_value = (int)((float)s_cpm / GEIGER_CPM_PER_USVH * 100.0f + 0.5f);
}

static int geiger_usvh_x100(void)
{
    return (int)((float)s_cpm * 100.0f / GEIGER_CPM_PER_USVH + 0.5f);
}

static void geiger_push_bucket(uint32_t delta)
{
    s_sec_buckets[s_bucket_idx] = delta;
    s_bucket_idx = (s_bucket_idx + 1) % GEIGER_CPM_WINDOW_SEC;
    geiger_recalc_cpm();
}

/* Оновлення раз на календарну секунду (не залежить від OLED/логу) */
static void geiger_commit_seconds(void)
{
    const int64_t sec = esp_timer_get_time() / 1000000LL;
    if (s_last_commit_sec < 0) {
        s_last_isr_total = s_pulse_isr_total;
        s_last_commit_sec = sec;
        return;
    }
    if (sec <= s_last_commit_sec) {
        return;
    }

    const uint32_t total = s_pulse_isr_total;
    const uint32_t delta = total - s_last_isr_total;
    s_last_isr_total = total;

    const int64_t skipped = sec - s_last_commit_sec;
    if (skipped == 1) {
        s_sec_pulse_count = delta;
        geiger_push_bucket(delta);
    } else {
        for (int64_t i = 1; i < skipped; i++) {
            geiger_push_bucket(0);
        }
        s_sec_pulse_count = delta;
        geiger_push_bucket(delta);
    }
    s_last_commit_sec = sec;
}

/* ── OLED: буфер у форматі SSD1306 (vertical page mapping) ─────────────────── */
static void oled_clear(void)
{
    memset(s_oled_buf, 0x00, sizeof(s_oled_buf));
}

static void oled_set_pixel(int x, int y, bool on)
{
    if (x < 0 || x >= OLED_WIDTH || y < 0 || y >= OLED_HEIGHT) {
        return;
    }
    uint8_t *byte = &s_oled_buf[(y >> 3) * OLED_WIDTH + x];
    if (on) {
        *byte |= (1 << (y & 7));
    } else {
        *byte &= ~(1 << (y & 7));
    }
}

static void oled_draw_char(int x, int y, char c)
{
    if (c < 32 || c > 127) {
        c = '?';
    }
    const uint8_t *glyph = font6x8[c - 32];
    for (int col = 0; col < FONT_CHAR_W - 1; col++) {
        uint8_t line = glyph[col];
        for (int row = 0; row < FONT_CHAR_H; row++) {
            if (line & (1 << row)) {
                oled_set_pixel(x + col, y + row, true);
            }
        }
    }
}

static void oled_draw_string(int x, int y, const char *text)
{
    int cursor = x;
    while (*text) {
        oled_draw_char(cursor, y, *text++);
        cursor += FONT_CHAR_W;
    }
}

static int oled_text_width(const char *text)
{
    int n = 0;
    while (*text++) {
        n++;
    }
    return n * FONT_CHAR_W;
}

static void oled_draw_char_scaled(int x, int y, char c, int scale)
{
    if (c < 32 || c > 127) {
        c = '?';
    }
    const uint8_t *glyph = font6x8[c - 32];
    for (int col = 0; col < FONT_CHAR_W - 1; col++) {
        uint8_t line = glyph[col];
        for (int row = 0; row < FONT_CHAR_H; row++) {
            if (line & (1 << row)) {
                for (int sy = 0; sy < scale; sy++) {
                    for (int sx = 0; sx < scale; sx++) {
                        oled_set_pixel(x + col * scale + sx, y + row * scale + sy, true);
                    }
                }
            }
        }
    }
}

static void oled_draw_string_scaled(int x, int y, const char *text, int scale)
{
    int cursor = x;
    while (*text) {
        oled_draw_char_scaled(cursor, y, *text++, scale);
        cursor += FONT_CHAR_W * scale;
    }
}

static int oled_string_scaled_width(const char *text, int scale)
{
    int len = 0;
    while (text[len]) {
        len++;
    }
    return len * FONT_CHAR_W * scale;
}

static void oled_clear_rect(int x0, int y0, int x1, int y1)
{
    for (int y = y0; y < y1; y++) {
        for (int x = x0; x < x1; x++) {
            oled_set_pixel(x, y, false);
        }
    }
}

static esp_err_t oled_flush(void)
{
    return esp_lcd_panel_draw_bitmap(s_panel, 0, 0, OLED_WIDTH, OLED_HEIGHT, s_oled_buf);
}

static bool oled_mutex_take(void)
{
    if (s_oled_mtx == NULL) {
        return false;
    }
    return xSemaphoreTake(s_oled_mtx, pdMS_TO_TICKS(500)) == pdTRUE;
}

static void oled_mutex_give(void)
{
    xSemaphoreGive(s_oled_mtx);
}

static void oled_flush_locked(void)
{
    for (int attempt = 0; attempt < 3; attempt++) {
        if (oled_flush() == ESP_OK) {
            return;
        }
        vTaskDelay(pdMS_TO_TICKS(20));
    }
}

/* Частковий flush — швидше за повний екран (менше I2C) */
static void oled_flush_region_locked(int x0, int y0, int x1, int y1)
{
    if (y0 < 0) {
        y0 = 0;
    }
    if (y1 > OLED_HEIGHT) {
        y1 = OLED_HEIGHT;
    }
    if (x0 < 0) {
        x0 = 0;
    }
    if (x1 > OLED_WIDTH) {
        x1 = OLED_WIDTH;
    }
    if (y0 >= y1 || x0 >= x1) {
        return;
    }

    const int page0 = y0 >> 3;
    const int page1 = (y1 - 1) >> 3;
    const int y_start = page0 * 8;
    const int y_end = (page1 + 1) * 8;
    const uint8_t *src = &s_oled_buf[page0 * OLED_WIDTH];

    for (int attempt = 0; attempt < 3; attempt++) {
        if (esp_lcd_panel_draw_bitmap(s_panel, x0, y_start, x1, y_end, src) == ESP_OK) {
            return;
        }
        vTaskDelay(pdMS_TO_TICKS(20));
    }
}

/* Іконка АКБ у верхньому правому куті */
static void oled_draw_battery_icon(int x, int y, int pct)
{
    const int bw = BAT_ICON_BODY_W;
    const int bh = BAT_ICON_BODY_H;

    for (int i = 0; i < bw; i++) {
        oled_set_pixel(x + i, y, true);
        oled_set_pixel(x + i, y + bh - 1, true);
    }
    for (int j = 1; j < bh - 1; j++) {
        oled_set_pixel(x, y + j, true);
        oled_set_pixel(x + bw - 1, y + j, true);
    }

    const int cap_y = y + (bh - BAT_ICON_CAP_H) / 2;
    for (int j = 0; j < BAT_ICON_CAP_H; j++) {
        for (int i = 0; i < BAT_ICON_CAP_W; i++) {
            oled_set_pixel(x + bw + i, cap_y + j, true);
        }
    }

    if (pct < 0) {
        return;
    }

    const int inner_w = bw - 2;
    const int fill_w = (inner_w * pct + 50) / 100;
    for (int i = 0; i < fill_w; i++) {
        for (int j = 1; j < bh - 1; j++) {
            oled_set_pixel(x + 1 + i, y + j, true);
        }
    }
}

static void oled_draw_battery_top_right(void)
{
    char pct_str[16];
    const int icon_w = BAT_ICON_BODY_W + BAT_ICON_CAP_W;

    if (s_bat_display_pct < 0) {
        snprintf(pct_str, sizeof(pct_str), "--%%");
    } else {
        snprintf(pct_str, sizeof(pct_str), "%d%%", s_bat_display_pct);
    }

    const int pct_w = oled_text_width(pct_str);
    const int total_w = icon_w + 2 + pct_w;
    const int x0 = OLED_WIDTH - total_w;
    const int y = 1;

    oled_clear_rect(x0 - 2, 0, OLED_WIDTH, UI_STATUS_H);
    oled_draw_battery_icon(x0, y, s_bat_display_pct);
    oled_draw_string(x0 + icon_w + 2, y, pct_str);
}

static void oled_draw_dose_main(void)
{
    char value[24];
    const char *unit = "CPM";

    switch (s_display_mode) {
    case 0:
        unit = "CPM";
        snprintf(value, sizeof(value), "%d", s_cpm_inst);
        break;
    case 2:
        unit = "cnt";
        snprintf(value, sizeof(value), "%lu", (unsigned long)s_pulse_isr_total);
        break;
    case 1: {
        unit = "uSv/h";
        const int usvh_x100 = geiger_usvh_x100();
        snprintf(value, sizeof(value), "%d.%02d", usvh_x100 / 100, usvh_x100 % 100);
        break;
    }
    default:
        unit = "CPM";
        snprintf(value, sizeof(value), "%d", s_cpm_inst);
        break;
    }

    oled_clear_rect(0, UI_STATUS_H, OLED_WIDTH, OLED_HEIGHT);
    oled_draw_string_scaled(UI_DOSE_X, UI_DOSE_Y, value, UI_DOSE_SCALE);
    const int unit_w = oled_text_width(unit);
    oled_draw_string(OLED_WIDTH - unit_w - UI_UNIT_MARGIN, UI_UNIT_Y, unit);
}

static void oled_refresh_dose(void)
{
    if (s_splash_active) {
        return;
    }
    if (!oled_mutex_take()) {
        return;
    }
    oled_draw_dose_main();
    oled_flush_region_locked(0, UI_STATUS_H, OLED_WIDTH, OLED_HEIGHT);
    oled_mutex_give();
}

static void oled_refresh_battery(void)
{
    if (s_splash_active) {
        return;
    }
    if (!oled_mutex_take()) {
        return;
    }
    oled_draw_battery_top_right();
    oled_flush_region_locked(0, 0, OLED_WIDTH, UI_STATUS_H);
    oled_mutex_give();
}

static void oled_draw_work_screen(void)
{
    if (!oled_mutex_take()) {
        return;
    }
    oled_clear();
    oled_draw_battery_top_right();
    oled_draw_dose_main();
    oled_flush_locked();
    oled_mutex_give();
}

static void oled_update_battery_corner(void)
{
    oled_refresh_battery();
}

static void oled_draw_splash(void)
{
    if (!oled_mutex_take()) {
        return;
    }
    memcpy(s_oled_buf, splash_bitmap, sizeof(splash_bitmap));
#if SPLASH_INVERT_COLORS
    for (size_t i = 0; i < sizeof(splash_bitmap); i++) {
        s_oled_buf[i] ^= 0xFF;
    }
#endif
    oled_flush_locked();
    oled_mutex_give();
}

static esp_err_t oled_init(void)
{
    i2c_master_bus_config_t bus_cfg = {};
    bus_cfg.i2c_port = I2C_NUM_0;
    bus_cfg.sda_io_num = PIN_OLED_SDA;
    bus_cfg.scl_io_num = PIN_OLED_SCL;
    bus_cfg.clk_source = I2C_CLK_SRC_DEFAULT;
    bus_cfg.glitch_ignore_cnt = 7;
    bus_cfg.flags.enable_internal_pullup = 1;
    ESP_RETURN_ON_ERROR(i2c_new_master_bus(&bus_cfg, &s_i2c_bus), TAG, "I2C bus init failed");

    esp_lcd_panel_io_handle_t io = NULL;
    esp_lcd_panel_io_i2c_config_t io_cfg = {};
    io_cfg.dev_addr = OLED_I2C_ADDR;
    io_cfg.control_phase_bytes = 1;
    io_cfg.dc_bit_offset = 6;
    io_cfg.lcd_cmd_bits = 8;
    io_cfg.lcd_param_bits = 8;
    io_cfg.scl_speed_hz = OLED_I2C_HZ;
    ESP_RETURN_ON_ERROR(esp_lcd_new_panel_io_i2c(s_i2c_bus, &io_cfg, &io), TAG, "panel IO failed");

    esp_lcd_panel_ssd1306_config_t ssd1306_cfg = {
        .height = OLED_HEIGHT,
    };
    esp_lcd_panel_dev_config_t panel_cfg = {};
    panel_cfg.reset_gpio_num = GPIO_NUM_NC;
    panel_cfg.rgb_ele_order = LCD_RGB_ELEMENT_ORDER_RGB;
    panel_cfg.data_endian = LCD_RGB_DATA_ENDIAN_BIG;
    panel_cfg.bits_per_pixel = 1;
    panel_cfg.vendor_config = &ssd1306_cfg;
    ESP_RETURN_ON_ERROR(esp_lcd_new_panel_ssd1306(io, &panel_cfg, &s_panel), TAG, "SSD1306 init failed");

    ESP_RETURN_ON_ERROR(esp_lcd_panel_reset(s_panel), TAG, "panel reset failed");
    ESP_RETURN_ON_ERROR(esp_lcd_panel_init(s_panel), TAG, "panel init failed");
    ESP_RETURN_ON_ERROR(esp_lcd_panel_disp_on_off(s_panel, true), TAG, "panel on failed");

    s_oled_mtx = xSemaphoreCreateMutex();
    if (s_oled_mtx == NULL) {
        return ESP_ERR_NO_MEM;
    }
    return ESP_OK;
}

/* ── АКБ: ADC на GPIO3 ─────────────────────────────────────────────────────── */
static bool battery_adc_calibration_init(void)
{
#if ADC_CALI_SCHEME_CURVE_FITTING_SUPPORTED
    adc_cali_curve_fitting_config_t cali_cfg = {
        .unit_id = ADC_UNIT_1,
        .chan = s_bat_channel,
        .atten = BAT_ADC_ATTEN,
        .bitwidth = ADC_BITWIDTH_12,
    };
    if (adc_cali_create_scheme_curve_fitting(&cali_cfg, &s_adc_cali_handle) == ESP_OK) {
        return true;
    }
#endif
    return false;
}

static void battery_adc_pin_scan(void)
{
    static const int scan_gpios[] = {0, 1, 3, 4}; /* не GPIO2 — там СИ-22Г */
    adc_oneshot_chan_cfg_t chan_cfg = {
        .atten = BAT_ADC_ATTEN,
        .bitwidth = ADC_BITWIDTH_12,
    };

    ESP_LOGI(TAG, "=== ADC scan at boot ===");
    for (int gpio : scan_gpios) {
        adc_unit_t unit = ADC_UNIT_1;
        adc_channel_t channel = ADC_CHANNEL_0;
        if (adc_oneshot_io_to_channel(gpio, &unit, &channel) != ESP_OK || unit != ADC_UNIT_1) {
            continue;
        }
        if (adc_oneshot_config_channel(s_adc_handle, channel, &chan_cfg) != ESP_OK) {
            continue;
        }

        int raw_sum = 0;
        for (int i = 0; i < 8; i++) {
            int raw = 0;
            if (adc_oneshot_read(s_adc_handle, channel, &raw) == ESP_OK) {
                raw_sum += raw;
            }
        }
        const int raw = raw_sum / 8;
        const int pin_mv = (raw * BAT_ADC_VREF_MV) / 4095;
        ESP_LOGI(TAG, "  GPIO%d ch%d raw=%d pin~%dmV", gpio, channel, raw, pin_mv);
    }

    ESP_ERROR_CHECK(adc_oneshot_config_channel(s_adc_handle, s_bat_channel, &chan_cfg));
}
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
extern "C" void app_main(void)
{
    ESP_LOGI(TAG, "System started");

    battery_adc_init();
    ESP_ERROR_CHECK(oled_init());
    led_init();
    buttons_init();
    buzzer_init();
    geiger_pulse_init();

    xTaskCreate(geiger_poll_task, "geiger_poll", 3072, NULL, 10, NULL);
    xTaskCreate(piezo_task, "piezo", 2048, NULL, 4, NULL);
    xTaskCreate(geiger_stats_task, "geiger", 3072, NULL, 6, NULL);
    xTaskCreate(app_task, "si22g_app", 4096, NULL, 5, NULL);
}
